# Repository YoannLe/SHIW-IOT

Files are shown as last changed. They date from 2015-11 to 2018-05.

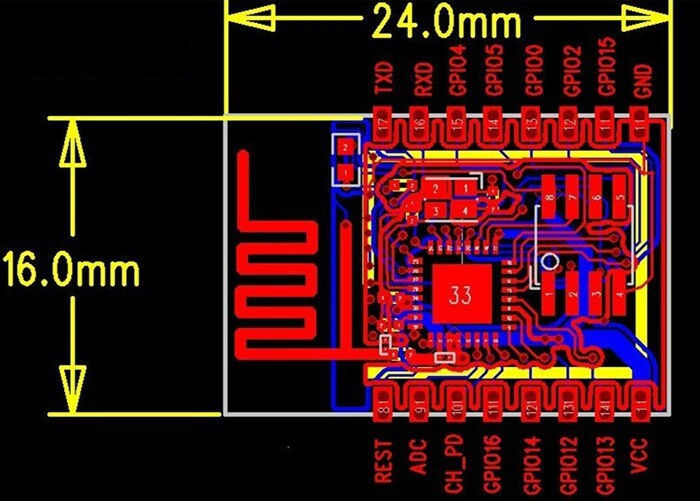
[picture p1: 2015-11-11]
Hardware/Datasheet/ESP-12-Pinout.jpg

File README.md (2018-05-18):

# SmartHome-In-Wall-IOT

Smart Home in-wall IOT modules with ESP8266 designed to be used with Arduino and REST API or Souliss, OpenHab,...

Goals and prospects:
* Modules must fit in standard electric wall boxes (European standard wallbox ⌀67x40mm)
* Limit the number of components for DIY feasibility
* Common logic board and different power boards

This GitHub contains PCB files and source code samples.

##Hardware
Schematic and PCB:
* Logic Board:
 * Made for ESP-07 or EPS-12 ESP8266 module
 * Drives all power boards
 * Include relay driver, I2C port for Temperatur and Humidity sensor
* Power Boards:
 * Relays version: Relays Board, 2 dual coils relays, for curtains, garage doors...
 * FilPilote version: Generate signals for drive Electric Heaters by Fil Pilote
 * Dimmer version: Triac with zero crossing circuit to dim incandescent lamps

##Software
Arduino source code sample for each module, can works out of the box but understanding Souliss architecture and configration is required to build a Smart Home Network with a lot of nodes.

##Documentation

##References
[Arduino and ESP8266 GitHub](https://github.com/esp8266/Arduino)

[Souliss Wiki](https://github.com/souliss/souliss/wiki) 

[Souliss Website](http://souliss.net/)

[Fil Pilote] (http://www.radiateur-electrique.org/fil-pilote-radiateur.php)

# License

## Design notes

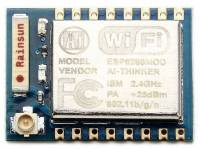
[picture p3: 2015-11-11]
Hardware/Datasheet/ESP-07-Picture.jpg

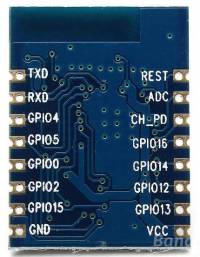
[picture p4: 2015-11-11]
Hardware/Datasheet/ESP-07-Pinout.jpg

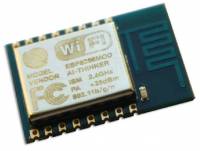
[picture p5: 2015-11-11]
Hardware/Datasheet/ESP-12-Picture.jpg

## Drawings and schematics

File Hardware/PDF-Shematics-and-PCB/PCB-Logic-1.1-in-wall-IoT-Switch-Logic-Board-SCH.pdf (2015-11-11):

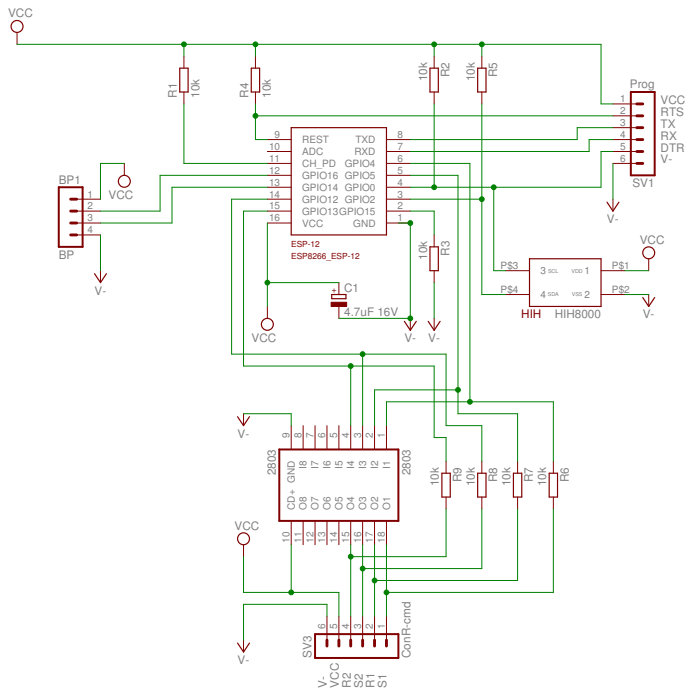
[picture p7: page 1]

4 GPIO5
3 GPIO0
2 GPIO2

16 | 1 GPIO15

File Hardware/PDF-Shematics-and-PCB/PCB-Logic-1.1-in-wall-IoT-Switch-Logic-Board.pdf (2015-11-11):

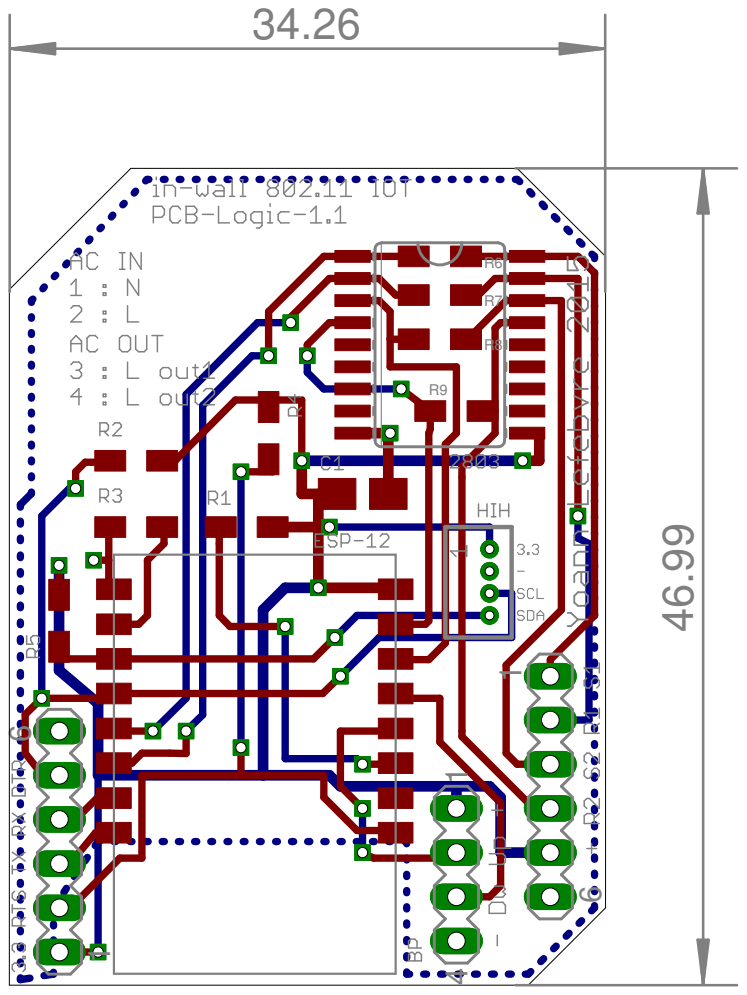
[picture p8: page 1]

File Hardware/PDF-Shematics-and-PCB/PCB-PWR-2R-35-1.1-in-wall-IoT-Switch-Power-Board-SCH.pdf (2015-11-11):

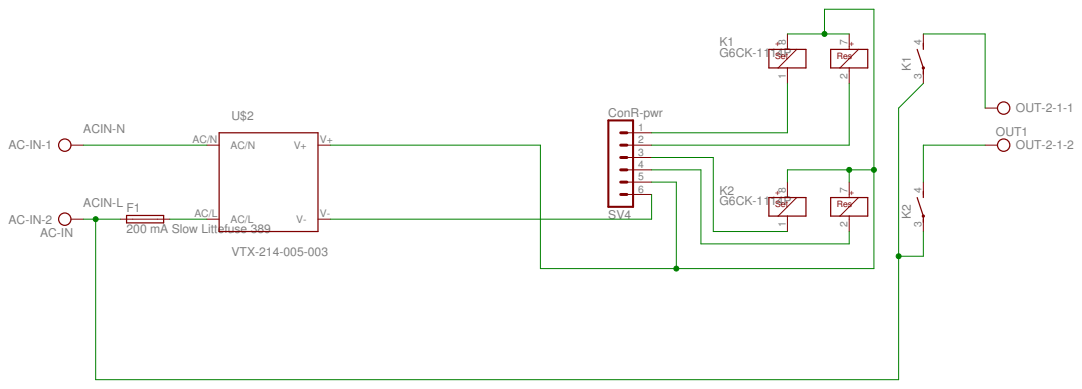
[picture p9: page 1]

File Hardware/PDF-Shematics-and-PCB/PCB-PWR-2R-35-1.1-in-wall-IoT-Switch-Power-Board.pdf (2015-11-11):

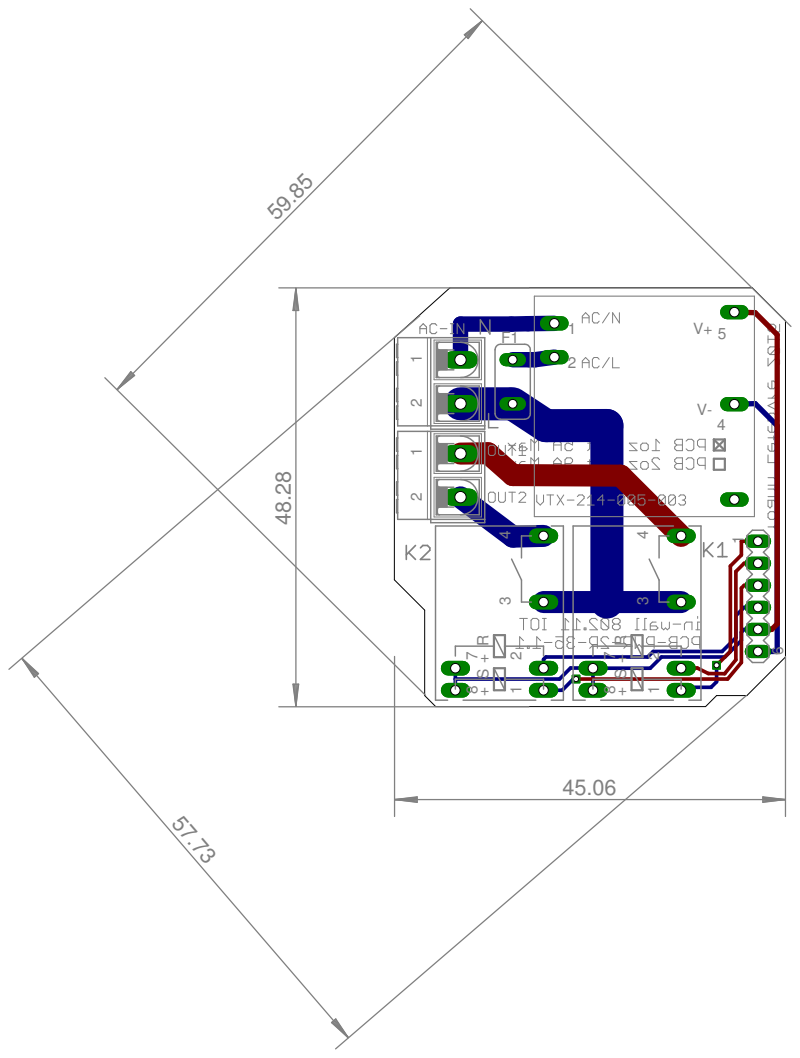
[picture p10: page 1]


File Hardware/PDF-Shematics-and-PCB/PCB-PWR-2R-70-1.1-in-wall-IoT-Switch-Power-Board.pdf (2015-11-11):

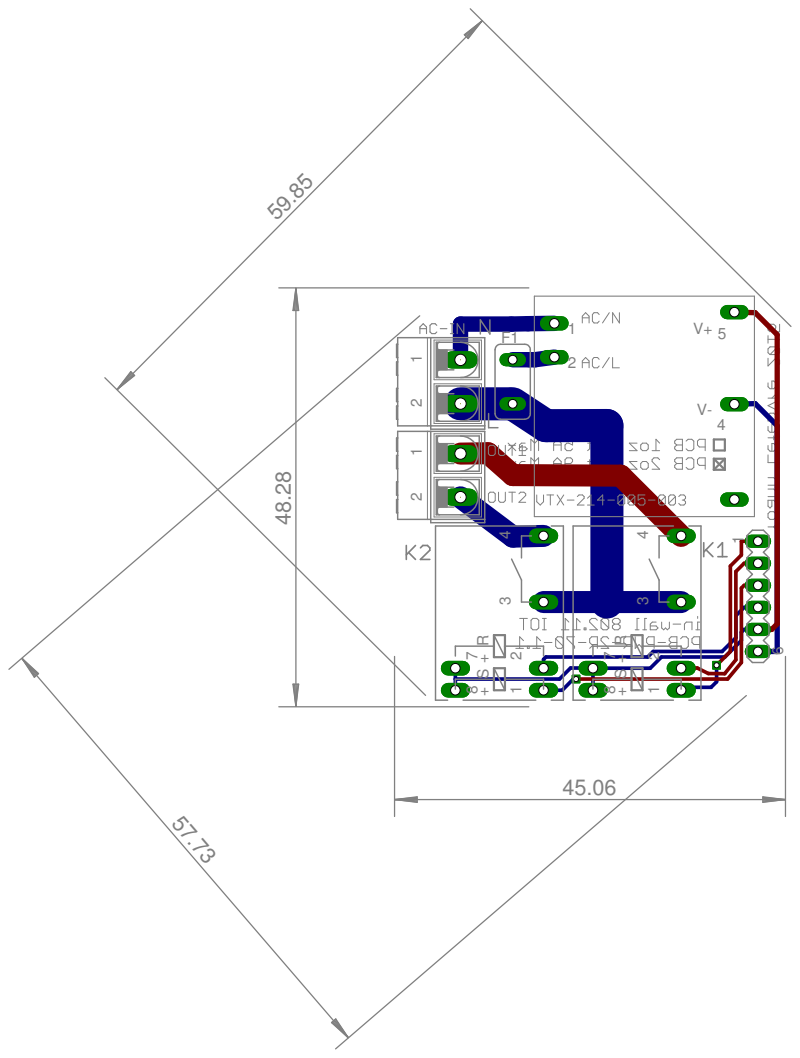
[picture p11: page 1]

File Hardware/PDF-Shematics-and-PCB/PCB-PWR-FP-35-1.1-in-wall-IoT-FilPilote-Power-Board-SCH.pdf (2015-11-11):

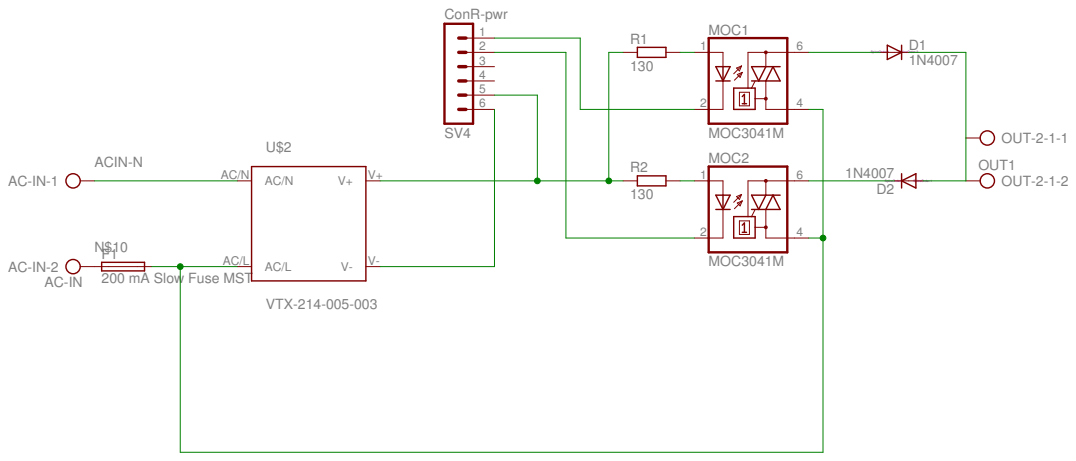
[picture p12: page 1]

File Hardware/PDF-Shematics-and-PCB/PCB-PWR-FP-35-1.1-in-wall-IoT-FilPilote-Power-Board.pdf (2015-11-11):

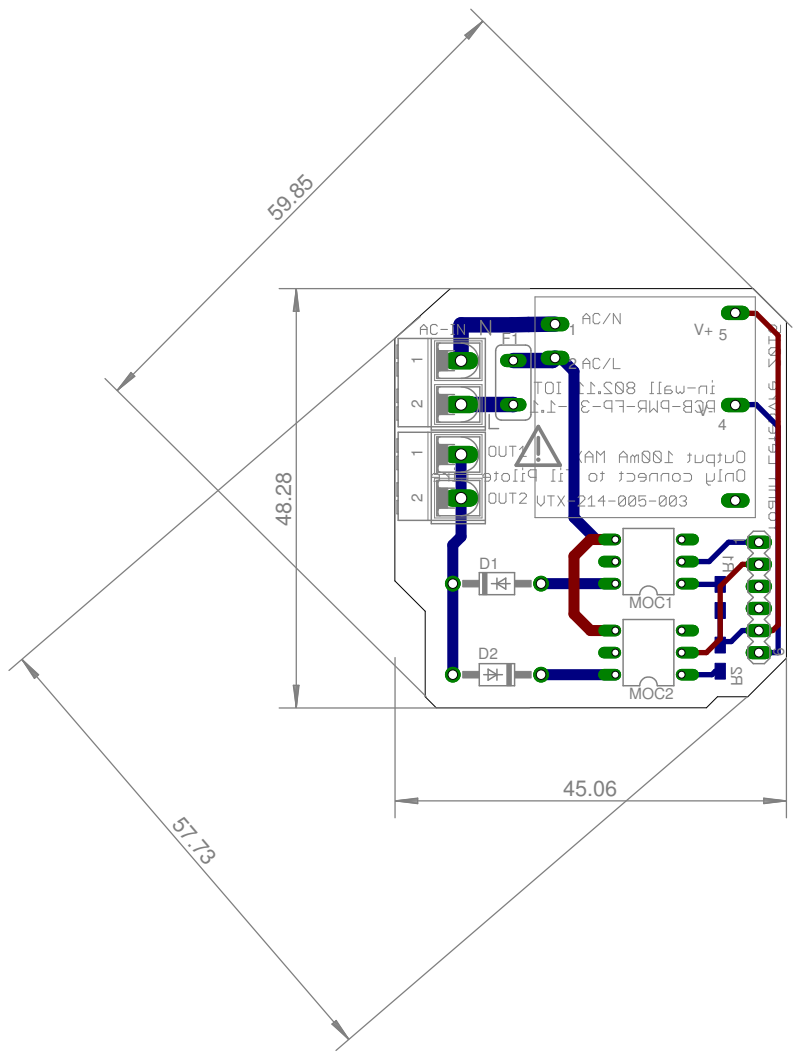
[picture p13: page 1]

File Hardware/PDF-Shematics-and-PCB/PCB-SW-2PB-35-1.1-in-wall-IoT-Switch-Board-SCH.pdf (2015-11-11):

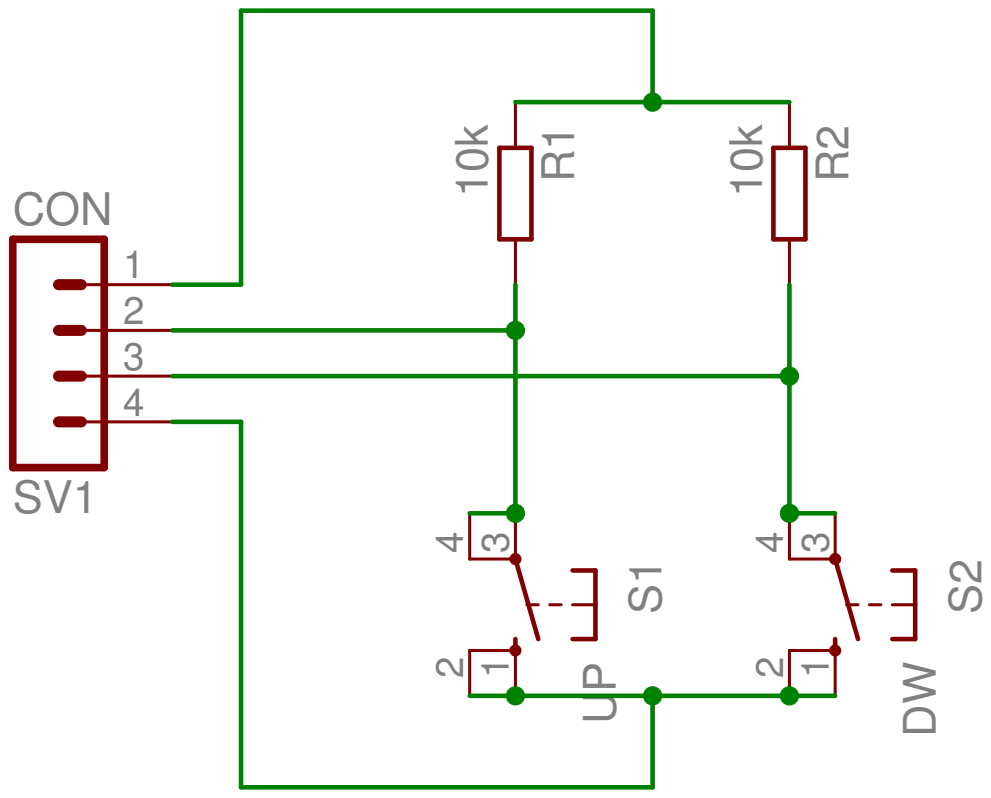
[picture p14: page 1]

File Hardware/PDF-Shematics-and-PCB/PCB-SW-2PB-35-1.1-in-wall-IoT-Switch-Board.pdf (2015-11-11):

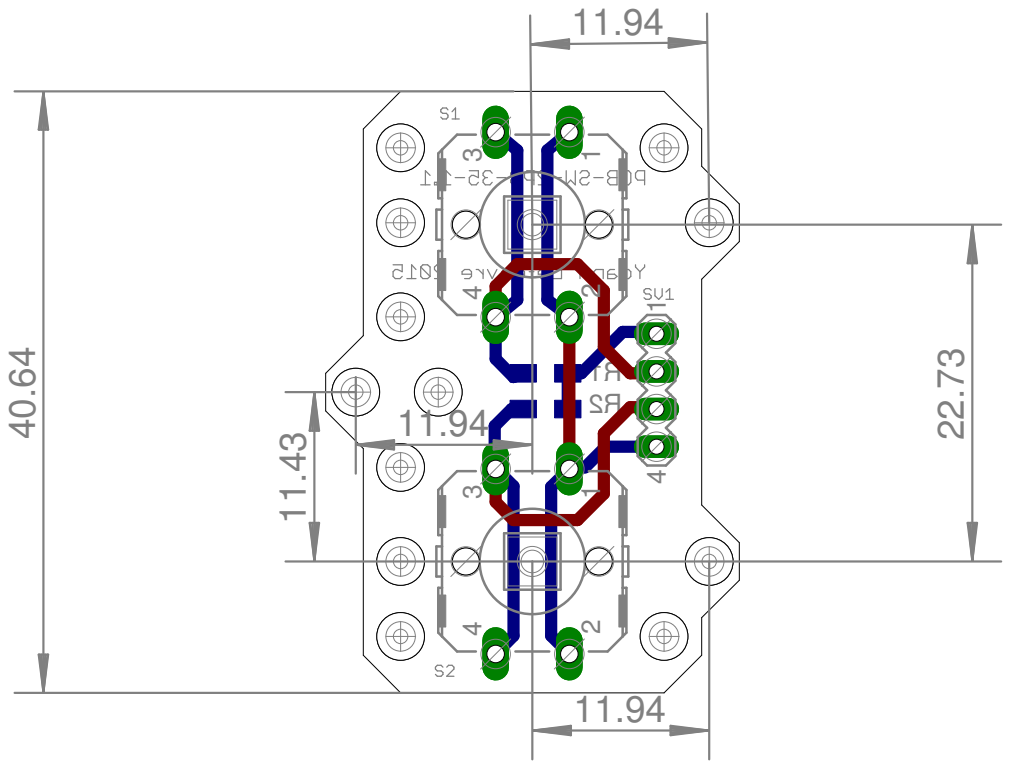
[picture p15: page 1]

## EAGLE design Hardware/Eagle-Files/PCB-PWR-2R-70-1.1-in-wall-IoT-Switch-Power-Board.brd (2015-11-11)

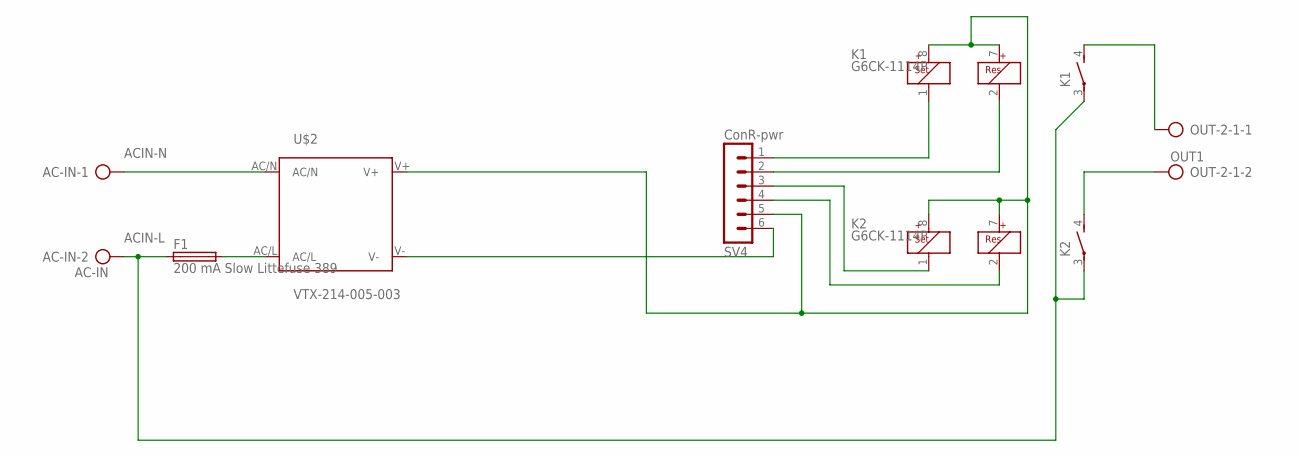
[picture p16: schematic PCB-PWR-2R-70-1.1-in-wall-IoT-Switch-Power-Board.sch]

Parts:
AC-IN: AC-IN; AK500/2-H
F1: 200 mA Slow Littefuse 389; TE5
K1, K2: G6CK-1114P; G6CK-1117P
OUT-2-1: OUT1; AK500/2-H
SV4: ConR-pwr; MA06-1
U$2: VTX-214-005-003

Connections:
ACIN-L: AC-IN.2, F1.1, K1.3, K2.3
ACIN-N: AC-IN.1, U$2.AC/N
unnamed: K1.4 (S), OUT-2-1.1
unnamed: K2.4 (S), OUT-2-1.2
unnamed: SV4.6, U$2.V-
unnamed: F1.2, U$2.AC/L
unnamed: K1.7 (R+), K1.8 (S+), K2.7 (R+), K2.8 (S+), SV4.5, U$2.V+
unnamed: K1.1 (S-), SV4.1
unnamed: K1.2 (R-), SV4.2
unnamed: K2.1 (S-), SV4.3
unnamed: K2.2 (R-), SV4.4

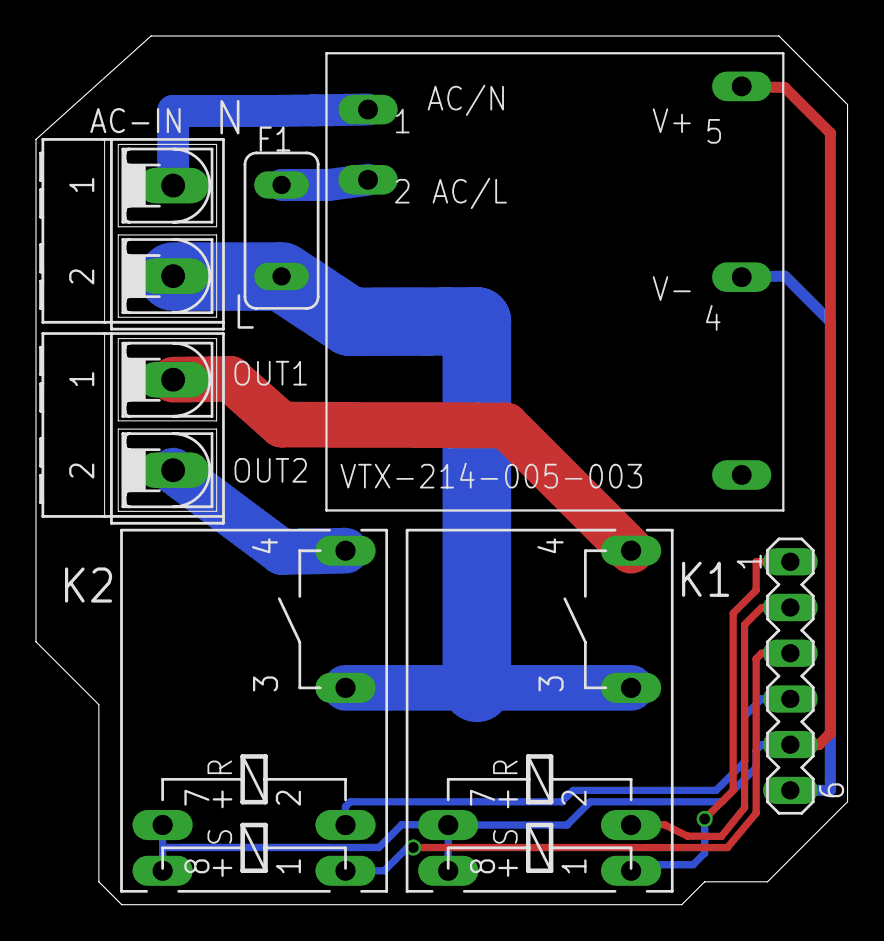
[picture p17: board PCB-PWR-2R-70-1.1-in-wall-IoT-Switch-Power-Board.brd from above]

Board: 2 copper layers, 45.1 x 48.3 mm, 7 parts (0 on the bottom side), 11 nets.

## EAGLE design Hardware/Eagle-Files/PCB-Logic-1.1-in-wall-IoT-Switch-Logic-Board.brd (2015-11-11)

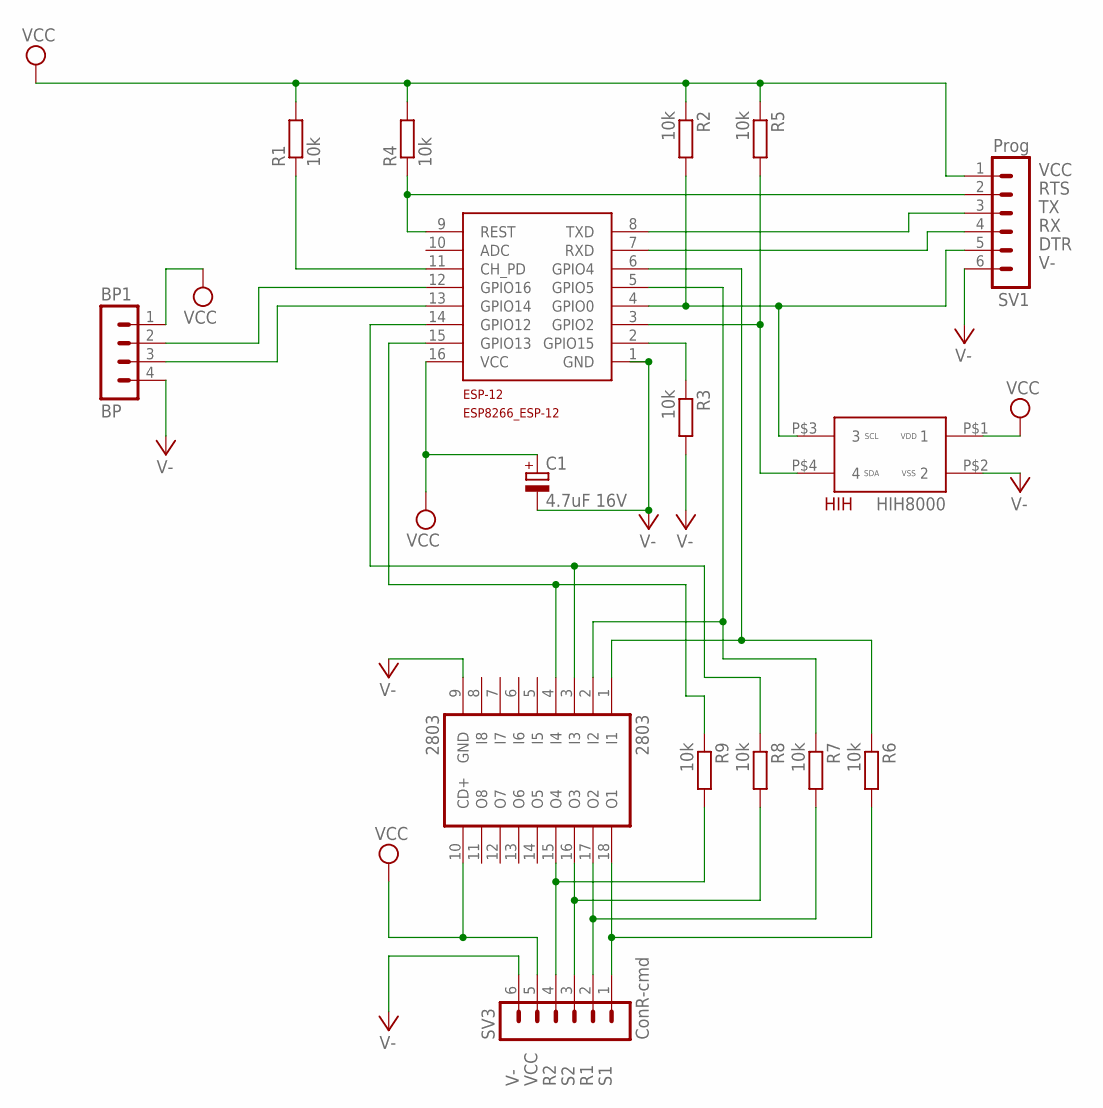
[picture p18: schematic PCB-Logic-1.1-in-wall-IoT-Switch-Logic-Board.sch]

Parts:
2803: 2803; SO18W
BP: BP1; MA04-1
C1: 4.7uF 16V; A/3216-18W
ESP-12: ESP8266_ESP-12; ESP8266-ESP12
HIH: HIH8120-021-001; SIP4
R1, R2, R3, R4, R5, R6, R7, R8, R9: 10k; R1206W
SV1: Prog; MA06-1
SV3: ConR-cmd; MA06-1

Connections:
BPDW: BP.3, ESP-12.13 (GPIO14)
BPUP: BP.2, ESP-12.12 (GPIO16)
DTR: ESP-12.4 (GPIO0), HIH.P$3 (3), R2.2, SV1.5
unnamed: ESP-12.3 (GPIO2), HIH.P$4 (4), R5.2
unnamed: ESP-12.2 (GPIO15), R3.1
unnamed: 2803.3 (I3), ESP-12.14 (GPIO12), R8.1
unnamed: 2803.4 (I4), ESP-12.15 (GPIO13), R9.1
unnamed: 2803.2 (I2), ESP-12.5 (GPIO5), R7.1
unnamed: ESP-12.11 (CH_PD), R1.1
unnamed: 2803.1 (I1), ESP-12.6 (GPIO4), R6.1
R1: 2803.17 (O2), R7.2, SV3.2
R2: 2803.15 (O4), R9.2, SV3.4
RTS: ESP-12.9 (REST), R4.1, SV1.2
RX: ESP-12.7 (RXD), SV1.4
S1: 2803.18 (O1), R6.2, SV3.1
S2: 2803.16 (O3), R8.2, SV3.3
TX: ESP-12.8 (TXD), SV1.3
V-: 2803.9 (GND), BP.4, C1.-, ESP-12.1 (GND), HIH.P$2 (2), R3.2, SV1.6, SV3.6
VCC: 2803.10 (CD+), BP.1, C1.+, ESP-12.16 (VCC), HIH.P$1 (1), R1.2, R2.1, R4.2, R5.1, SV1.1, SV3.5

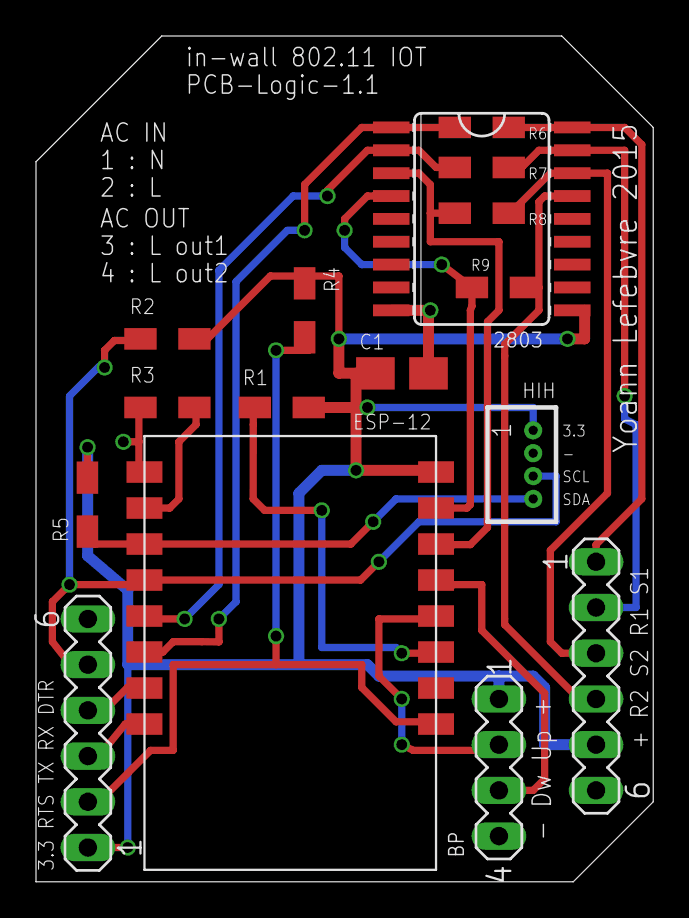
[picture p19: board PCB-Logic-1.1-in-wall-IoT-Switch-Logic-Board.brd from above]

Board: 2 copper layers, 34.3 x 47.0 mm, 16 parts (0 on the bottom side), 19 nets.

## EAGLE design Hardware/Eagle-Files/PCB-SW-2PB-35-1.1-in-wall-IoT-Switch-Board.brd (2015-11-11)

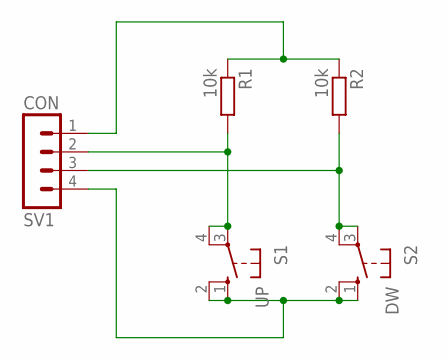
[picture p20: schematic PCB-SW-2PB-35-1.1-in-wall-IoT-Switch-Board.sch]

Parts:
R1, R2: 10k; R1206W
S1: UP; B3F-40XX
S2: DW; B3F-40XX
SV1: CON; MA04-1

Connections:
unnamed: R2.2, S2.3, S2.4 (P1), SV1.3
unnamed: R1.2, S1.3, S1.4 (P1), SV1.2
unnamed: R1.1, R2.1, SV1.1
unnamed: S1.1 (S), S1.2 (S1), S2.1 (S), S2.2 (S1), SV1.4

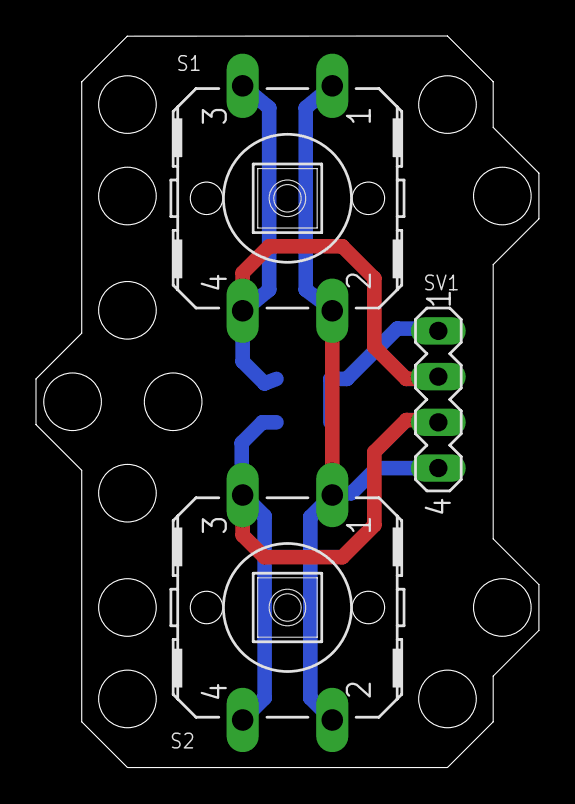
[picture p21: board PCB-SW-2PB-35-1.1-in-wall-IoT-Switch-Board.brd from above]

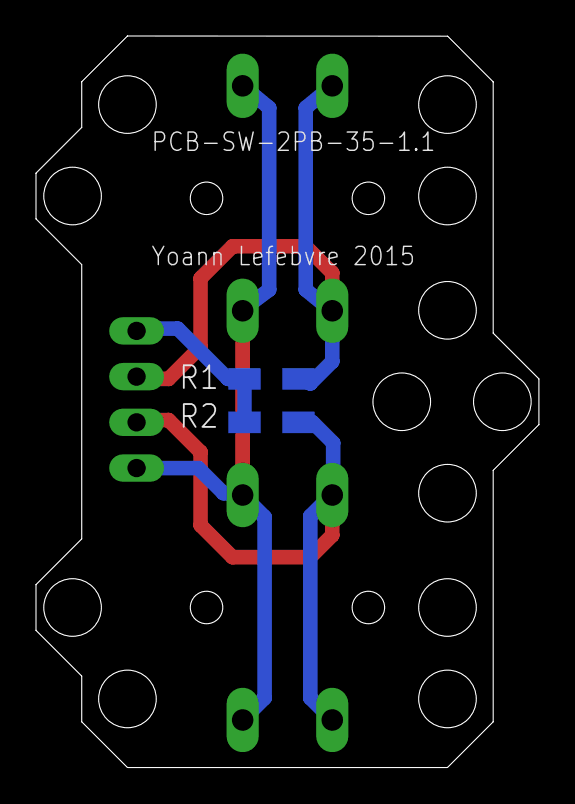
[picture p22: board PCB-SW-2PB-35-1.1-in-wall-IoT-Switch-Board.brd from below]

Board: 2 copper layers, 27.9 x 40.6 mm, 5 parts (2 on the bottom side), 4 nets.

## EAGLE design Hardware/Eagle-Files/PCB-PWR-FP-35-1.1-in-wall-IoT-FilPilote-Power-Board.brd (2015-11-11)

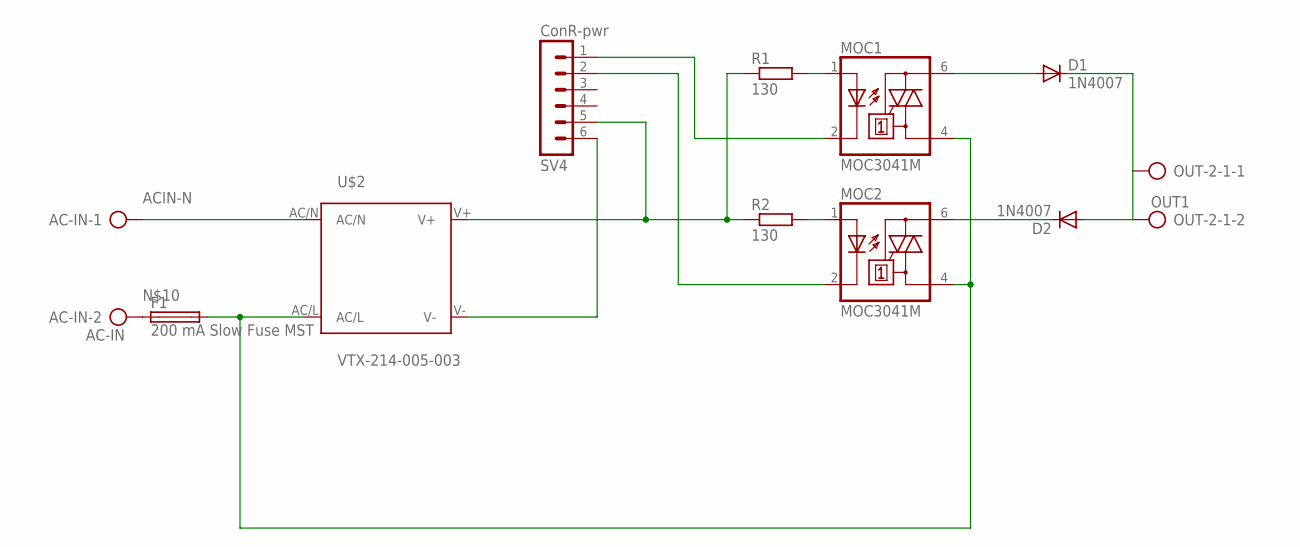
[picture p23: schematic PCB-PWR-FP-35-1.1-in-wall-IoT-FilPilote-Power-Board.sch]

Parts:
AC-IN: AC-IN; AK500/2-H
D1, D2: 1N4007; DO41-10
F1: 200 mA Slow Fuse MST; TE5
MOC1, MOC2: MOC3041M; DIL06
OUT-2-1: OUT1; AK500/2-H
R1, R2: 130; R1206W
SV4: ConR-pwr; MA06-1
U$2: VTX-214-005-003

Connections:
ACIN-L: F1.2, MOC1.4 (A1), MOC2.4 (A1), U$2.AC/L
ACIN-N: AC-IN.1, U$2.AC/N
unnamed: D1.C, D2.A, OUT-2-1.1, OUT-2-1.2
unnamed: D1.A, MOC1.6 (A2)
unnamed: SV4.6, U$2.V-
unnamed: D2.C, MOC2.6 (A2)
unnamed: MOC1.2 (C), SV4.1
unnamed: MOC2.2 (C), SV4.2
unnamed: MOC1.1 (A), R1.2
unnamed: MOC2.1 (A), R2.2
unnamed: AC-IN.2, F1.1
unnamed: R1.1, R2.1, SV4.5, U$2.V+

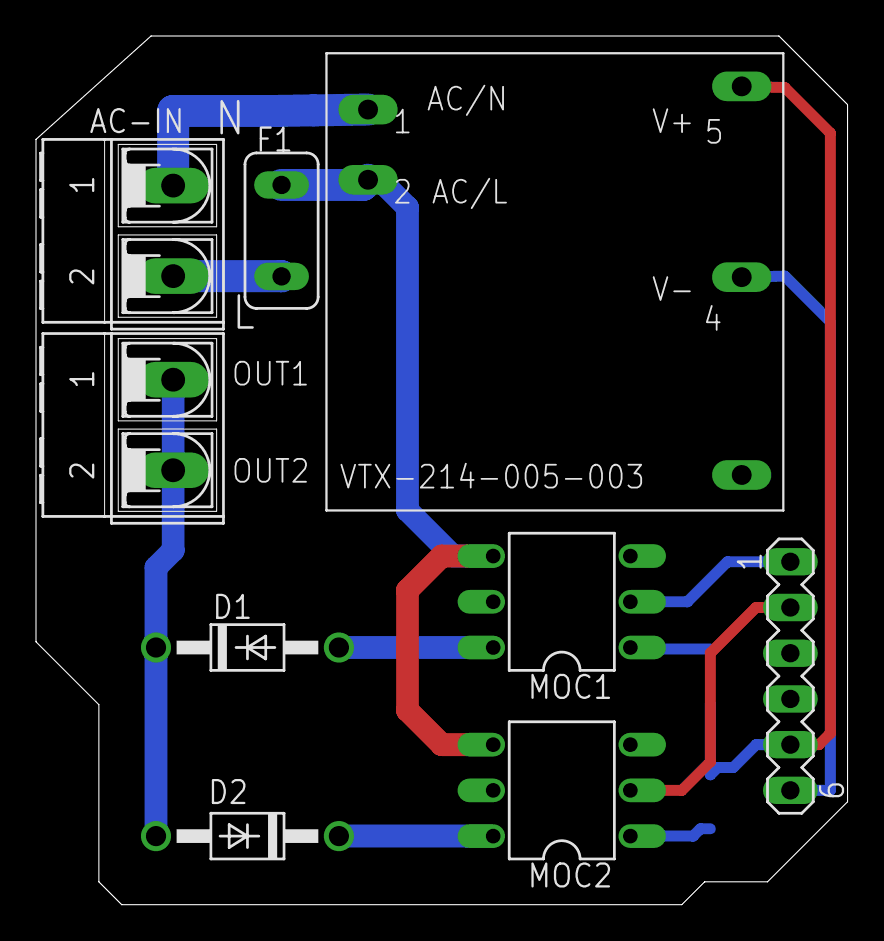
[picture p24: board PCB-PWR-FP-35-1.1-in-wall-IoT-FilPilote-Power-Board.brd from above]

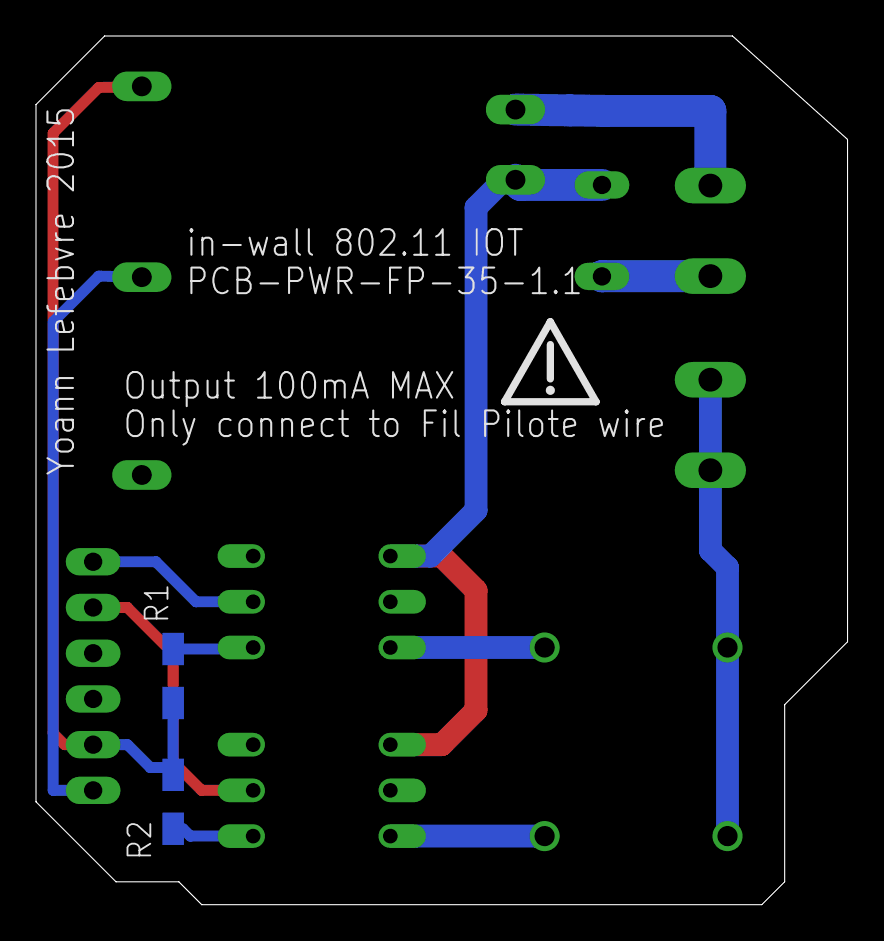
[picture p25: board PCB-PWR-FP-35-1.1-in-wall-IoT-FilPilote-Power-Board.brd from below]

Board: 2 copper layers, 45.1 x 48.3 mm, 11 parts (2 on the bottom side), 12 nets.

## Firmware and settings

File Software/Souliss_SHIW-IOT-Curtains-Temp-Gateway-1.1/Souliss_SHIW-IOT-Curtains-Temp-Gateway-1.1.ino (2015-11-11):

/**************************************************************************
    Smart Home In Wall IOT - SHIW-IOT 1.1

    Souliss 7.1.0
    
    Use with SHIW-IOT boards 1.1 
    Logic Board: PCB-Logic-1.1
    Power Relays Board:PCB-PWR-2R-35-1.1 / PCB-PWR-2R-70-1.1

    This board can drive motorised curtains with local push buttons
    Includes Temperature / Humidity sensor HIH8120-021-001S

    Schematic uses ESP-07 or EPS-12 pinouts, on this program ESP-12E have been
    used, GPIO4 and GPIO5 are swapped on ESP-12E, take into consideration
    at pin declaration.
    
    Load this code on ESP8266 board using the porting of the Arduino core
    for this platform.

    Yoann Lefebvre 2015.
        
***************************************************************************/


//-----------------USER CONFGURATION--------------------------------------------------------------

// Comment Souliss gateway settings in void setup() if souliss gateway is present

// **** Define the WiFi name and password ****
#define WIFICONF_INSKETCH
#define WiFi_SSID               "Your-WiFi-SSID"
#define WiFi_Password           "Your-WiFi-WPA-Key"  

//-----------------END OF USER CONFGURATION-------------------------------------------------------


// Configure the framework
#include "bconf/MCU_ESP8266.h"              // Load the code directly on the ESP8266
#include "conf/Gateway.h"                   // The main node is the Gateway, we have just one node
#include "conf/IPBroadcast.h"

// Include framework code and libraries
#include <ESP8266WiFi.h>
#include <EEPROM.h>
#include "Souliss.h"

//I2C
#include <Wire.h>

// This identify the number of the logic
#define CURTAIN0          0   //T22     1 slot
#define TEMPERATURE       1   //T52 T°  2 slots: 1 & 2
#define HUMIDITY          4   //T53 H   2 slots: 4 & 5

// Define delay to close or open
//#define Souliss_T2n_Timer_Val 10

// **** Define here the right pin for your ESP module ****
// OUT1/R1 for openning motor
// OUT2/R2 for cosing motor


//--------------------ESP Pinout version------------------------------
//ESP-07 or ESP-12
//#define  OS1		4   //SET relay 1 (LOW = Coil enable) = out1 active
//#define  OR1    5   //RESET relay 1 (LOW = Coil enable)

//ESP-12E alternativ: pin swap
#define  OS1    5   //SET relay 1 (LOW = Coil enable) = out1 active
#define  OR1    4   //RESET relay 1 (LOW = Coil enable)
//--------------------------------------------------------------------

#define  OS2   12   //SET relay 2 (LOW = Coil enable) = out2 active
#define  OR2   13   //RESET relay 2 (LOW = Coil enable)
#define  BUP   16   //Button UP
#define  BDW   14   //Button DOWN

//Temp / Humidity HIH8120-021-001S
#define  SDA    2
#define  SCL    0

byte fetch_humidity_temperature(unsigned int *p_Humidity, unsigned int *p_Temperature);

//Deadba,d T° & H
#define  DEADBAND   0.05

//Status of outputs
#define OUT_STOP 0
#define OUT_OPENING 1
#define OUT_CLOSING 2
#define OUT_OPEN 3
#define OUT_CLOSE 4

int outStatus = OUT_STOP;

void setup()
{   
    Initialize();

    // 2 coils Relays
    pinMode(OS1, OUTPUT);         // Use pin as output R1 Set
    pinMode(OR1, OUTPUT);         // Use pin as output R1 Reset
    pinMode(OS2, OUTPUT);         // Use pin as output R2 Set
    pinMode(OR2, OUTPUT);         // Use pin as output R2 Reset
    
    //Shuttdown relays outputs
    out1OFF();
    out2OFF();
       
    //command buttons Open and Close
    pinMode(BUP, INPUT);          // Use pin as intput
    pinMode(BDW, INPUT);          // Use pin as intput 

    Wire.begin(SDA, SCL);
    pinMode(SDA, OUTPUT);
    digitalWrite(4, HIGH);      // this turns on the HIH
    delay(5000);
    

    // Connect to the WiFi network and get an address from DHCP
    GetIPAddress();

    // This is the vNet address for this node, used to communicate with other
    // nodes in your Souliss network, based on IP set by DHCP Wifi network
    SetAddress(myvNet_dhcp, 0xFF00, 0x0000);


//-----------------GATEWAY CONFGURATION--------------------------------------------------------------
    //Comment this lock if a souliss gateway is present in network
    //Use for standalone testing
    
    // Set this node as gateway for SoulissApp
    SetAsGateway(myvNet_dhcp);
    // Register node TYPIALS in gateway
    SetAsPeerNode(myvNet_dhcp, 0);  //T22  slot
    SetAsPeerNode(myvNet_dhcp, 1);  //T52 T° 2 slots: 1 & 2
    SetAsPeerNode(myvNet_dhcp, 4);  //T53 H  2 slots: 4 & 5

//-----------------END OF GATEWAY CONFGURATION-------------------------------------------------------
    
    
    // define Typicals of this node
    Set_T22(CURTAIN0);      // Typical 22 : Motorized devices with limit switches and middle position
    Set_T52(TEMPERATURE);   // Typical 52 : Temperature measure (-20, +50) °C
    Set_T53(HUMIDITY);      // Typical 53 : Humidity measure (0, 100) %
  
    
}

void loop()
{   
    //Var T° & H
    byte _status;
    unsigned int H_dat, T_dat;
    float RH, T_C;

  
    // Here we start to play
    EXECUTEFAST() {                     
        UPDATEFAST();   

        // Process every 510ms the logic that control the curtain
        FAST_510ms() {
          
            // Update T° et H
            fetch_humidity_temperature(&H_dat, &T_dat);
            RH = (float) H_dat * 6.10e-3;
            T_C = (float) T_dat * 1.0072e-2 - 40.0;
            ImportAnalog(TEMPERATURE, &T_C);
            ImportAnalog(HUMIDITY, &RH);
          
            // Use OPEN and CLOSE BP Commands
            LowDigIn(BUP, Souliss_T2n_OpenCmd_Local, CURTAIN0);
            LowDigIn(BDW, Souliss_T2n_CloseCmd_Local, CURTAIN0);
            
            // Run the logic
            Logic_T22(CURTAIN0);
            Logic_T52(TEMPERATURE);
            Logic_T53(HUMIDITY);
            
            // Control the output relays, the stop is with both the relays not active.
            //T22 Output status:
            //1(hex) for CLOSING,
            //2(hex) for OPENING,
            //3(hex) for STOP.
            //8(hex) for CLOSE
            //10(hex for OPEN
            //
            //Status of board outputs
            //#define OUT_STOP 0
            //#define OUT_OPENING 1
            //#define OUT_CLOSING 2
            //#define OUT_OPEN 3
            //#define OUT_CLOSE 4
            
            //1(hex) for CLOSING
            if((mOutput(CURTAIN0) == 0x01) && (outStatus != OUT_CLOSING))
            {
              out1OFF();             
              out2ON();
              outStatus = OUT_CLOSING;
            }

            //2(hex) for OPENING
            if((mOutput(CURTAIN0) == 0x02) && (outStatus != OUT_OPENING))
            {
              out1ON();
              out2OFF();
              outStatus = OUT_OPENING;
            }

            //3(hex) for STOP
            if((mOutput(CURTAIN0) == 0x03) && (outStatus != OUT_STOP))
            {
              out1OFF();            
              out2OFF();
              outStatus = OUT_STOP;
            }
            
            //8(hex) for CLOSE
            if((mOutput(CURTAIN0) == 0x08) && (outStatus != OUT_CLOSE))
            {
              out1OFF();            
              out2OFF();
              outStatus = OUT_CLOSE;
            }
            
            //10(hex for OPEN
            if((mOutput(CURTAIN0) == 0x10) && (outStatus != OUT_OPEN))
            {
              out1OFF();            
              out2OFF();
              outStatus = OUT_OPEN;
            }
        } 

        // Process the communication
        FAST_PeerComms();
        // Here we handle here the communication with Gateway
        FAST_GatewayComms();  
    
        // Define the hold time of the outputs, by default the timer hold the relays for 16 times, so:
        // 221x10x16ms that is about 35 seconds. Change the parameter inside FAST_x10ms() to change this time.
        FAST_x10ms(50) {                 
            Timer_T22(CURTAIN0);
        }
    }
}

byte fetch_humidity_temperature(unsigned int *p_H_dat, unsigned int *p_T_dat)
{
      byte address, Hum_H, Hum_L, Temp_H, Temp_L, _status;
      unsigned int H_dat, T_dat;
      address = 0x27;;
      Wire.beginTransmission(address); 
      Wire.endTransmission();
      delay(100);
      
      Wire.requestFrom((int)address, (int) 4);
      Hum_H = Wire.read();
      Hum_L = Wire.read();
      Temp_H = Wire.read();
      Temp_L = Wire.read();
      Wire.endTransmission();
      
      _status = (Hum_H >> 6) & 0x03;
      Hum_H = Hum_H & 0x3f;
      H_dat = (((unsigned int)Hum_H) << 8) | Hum_L;
      T_dat = (((unsigned int)Temp_H) << 8) | Temp_L;
      T_dat = T_dat / 4;
      *p_H_dat = H_dat;
      *p_T_dat = T_dat;
      return(_status);
}

void out1ON()
{
  //enable R1 relay
  digitalWrite(OR1, LOW);
  digitalWrite(OS1, HIGH);
  delay(40);
  digitalWrite(OS1, LOW);
}

void out2ON()
{
  //enable R2 relay
  digitalWrite(OR2, LOW);
  digitalWrite(OS2, HIGH);
  delay(40);
  digitalWrite(OS2, LOW);
}

void out1OFF()
{
  //disable R1 relay
  digitalWrite(OS1, LOW);
  digitalWrite(OR1, HIGH);
  delay(40);
  digitalWrite(OR1, LOW);
}

void out2OFF()
{
  //disable R2 relay
  digitalWrite(OS2, LOW);
  digitalWrite(OR2, HIGH);
  delay(40);
  digitalWrite(OR2, LOW);
}

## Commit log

2015-11-11 Hardwares files
    [PCB-Logic-1.1-in-wall-IoT-Switch-Logic-Board.GBL, PCB-Logic-1.1-in-wall-IoT-Switch-Logic-Board.GBO, PCB-Logic-1.1-in-wall-IoT-Switch-Logic-Board.GBP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]
2015-11-11 Arduino souliss sample file
